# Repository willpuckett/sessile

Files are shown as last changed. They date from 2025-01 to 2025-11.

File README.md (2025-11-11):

# 🧽 Sessile

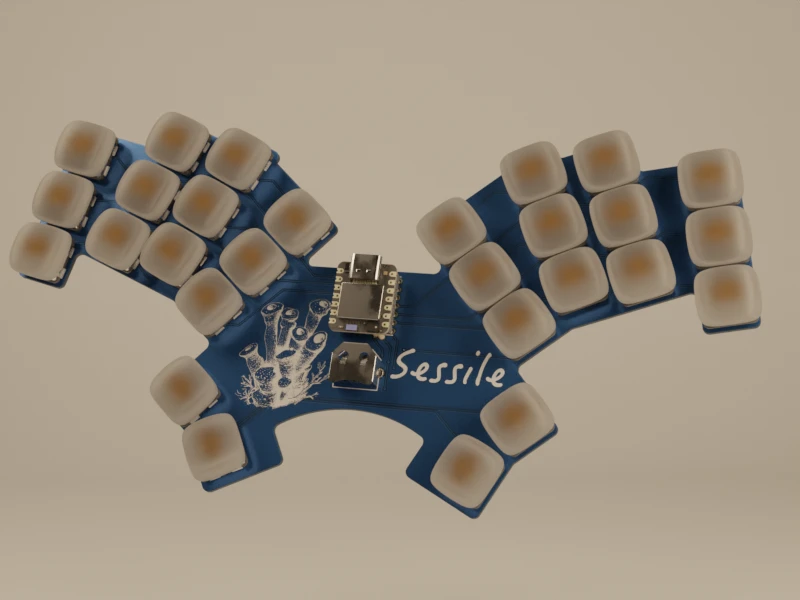
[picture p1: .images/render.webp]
sessile render








_Sessile_ is a further exploration of "minimal" finger travel.

## 🤔 What Even Is 'Minimal Finger Travel' Anyway?

Probably the least amount of finger travel would be not moving them at all. That
would be 10 keys...

```math
combos_{10\,keys} = \sum_{r=1}^{10} C(10, r) = 1023
```

...yielding **1023** possible combinations.

More realistically, we might consider excluding cross hand combinations so that
modifiers might be used. That would give us

```math
combos_{5\,keys} = \sum_{r=1}^{5} C(5, r) = 31
```

So, with only 5 keys on both hands, and no cross hand combos, we would have a
total of **62** possible keys per layer—more than sufficient.

I wasn't quite ready to take on learning to type on that though, so just
avoiding lateral reaches seemed like a start. 🙃

## ✨ Features

- 🧩 Sessile uses
  [KLP-Lame keycaps](https://github.com/braindefender/KLP-Lame-Keycaps). Larger
  caps may be tight, especially on the bottom row. I was lazy and didn't model
  the tilted keycaps in the rendering, but they're much nicer for the vertical
  combos.

- 🔋 Uses battery LIR1254. **DO NOT substitute LR44.**

- 🔌 The high speed pins were left available for encoders and _could_ be wired
  in a subsequent revision.

- ⚙️ Built for RMK. Configure using [Vial](https://get.vial.today).

## 🏠 Case

A 3D printable case is available in the
[latest release](https://github.com/willpuckett/sessile/releases/latest)! The
case is designed to sit as low as possible and can be secured with a stroke of
glue stick underneath. Case is generated via ergogen with jscad v2 api.
[Try it out](https://github.com/ergogen/ergogen/pull/159) it's testing 10-20x
faster than @jscad/cli@1.



## 📦 Production Files

Ready to manufacture your own board? All production files are included in the
repository:



Includes gerbers, BOM, and CPL files for JLC. Finished boards are ~~available~~
[sold out](https://octule.com/listing/1842172090/sessile) till the next batch.

## 🎨 Origin

_Sessile_ was produced using
[studyofhands](https://github.com/willpuckett/studyofhands).

study of hands

## 🚀 Firmware

This board is designed for RMK. 😏

### 🦀 RMK

Current RMK build is available in the
[Releases](https://github.com/willpuckett/sessile/releases/latest).

You can build the firmware yourself by cloning this repository and running

```bash
cd rmk && cargo make uf2 --release
```

> [!TIP]
> If you haven't previously used Rust to build software for nRF52840, you may
> need to follow the
> [Setup RMK Environment](https://rmk.rs/guide/user_guide/2-2_local_compilation#setup-rmk-environment)
> instructions.

## 🗺️ Keymap

<div align="center">

Caster Befuddle Variant

Generated with
[keymap-drawer](https://github.com/caksoylar/keymap-drawer/tree/main).

Physical layout imported from KiCad via
[keymap-layout-tools](https://nickcoutsos.github.io/keymap-layout-tools/).

</div>

## 🔌 Matrix Diagram

Sessile uses the following pinout for its matrix:

sessile_matrix

> [!NOTE]
> Referencing
> [this pinout sheet provided by Seeed](https://files.seeedstudio.com/wiki/XIAO-BLE/XIAO-nRF52840-pinout_sheet.xlsx),
> the only two exposed high speed pins P0_04/SDA/D4 & P0_05/SCL/D5 have been
> left available for possible encoders in a subsequent revision.

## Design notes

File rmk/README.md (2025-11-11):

# 🦀 RMK Firmware






## 🚀 Building

Automated builds of RMK are available in
[releases](https://github.com/willpuckett/sessile/releases/latest).

Once flashed, they can be configured via [Vial](https://get.vial.today).

### 🛠️ Build It Yourself

If you wish to build RMK yourself:

1. 📦 Install Rust: https://rustup.rs
2. 🎯 Add the target: `rustup target add thumbv7em-none-eabihf`
3. 🔧 Install tools: `cargo install flip-link cargo-make`
4. 🏗️ Build: `cd rmk && cargo make uf2 --release`
5. 📤 Flash: Double tap the button on your XIAO to enter the bootloader and drag
   the `.uf2` file to the mounted disk

## 💡 Tips for nRF52840

Most nice!nano compatible boards have a bootloader with SoftDevice pre-flashed.

> [!CAUTION]
> Since v0.7.x, RMK removes the old SoftDevice Bluetooth stack and replaces it
> with its own.
>
> If you want to rollback to v0.6.x, or switch to firmwares that use the
> SoftDevice stack (for example, ZMK), you will need to
> [re-flash the bootloader](https://github.com/willpuckett/sessile?tab=readme-ov-file#zmk).

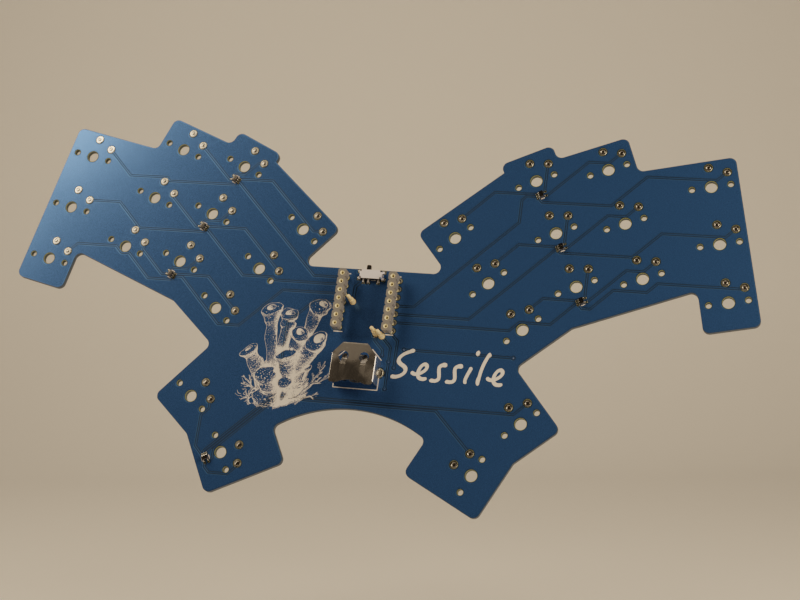
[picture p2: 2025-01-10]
.images/render_board.png

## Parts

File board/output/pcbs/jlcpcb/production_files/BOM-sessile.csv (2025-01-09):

Comment | Designator | Footprint | LCSC | Quantity
mill-max-3305-0-15-01-47-XX-10-0 | J10,J11,J12,J13,J14,J15,J16,J17,J18,J19,J20,J21,J22,J23,J24,J25,J26,J27,J28,J29,J30,J31,J32,J33,J34,J35,J36,J37,J38,J39,J4,J40,J41,J42,J43,J44,J45,J46,J47,J48,J49,J5,J50,J51,J52,J53,J54,J55,J56,J57,J58,J59,J6,J7,J8,J9 | mill-max-3305-0-15-01-47-XX-10-0 | C17370797 | 56
 | SW1 | power_switch | C221841 | 1
HDR-TH_7P-P2.54-V-F_MF254V-11-07-0743 | J60,J61 | HDR-TH_7P-P2.54-V-F_MF254V-11-07-0743 | C2889988 | 2
UMP1NTR | D3,D4,D5,D6,D7,D8,D9 | SOT-353_L2.1-W1.3-P0.65-LS2.3-BL | C510065 | 7
0906-2-15-20-75-14-11-0 | J1,J2,J3 | 0906-2-15-20-75-14-11-0 | C5261048 | 3
CONN-TH_MY-LR44-03-J | BAT1 | CONN-TH_MY-LR44-03-J | C5457116 | 1

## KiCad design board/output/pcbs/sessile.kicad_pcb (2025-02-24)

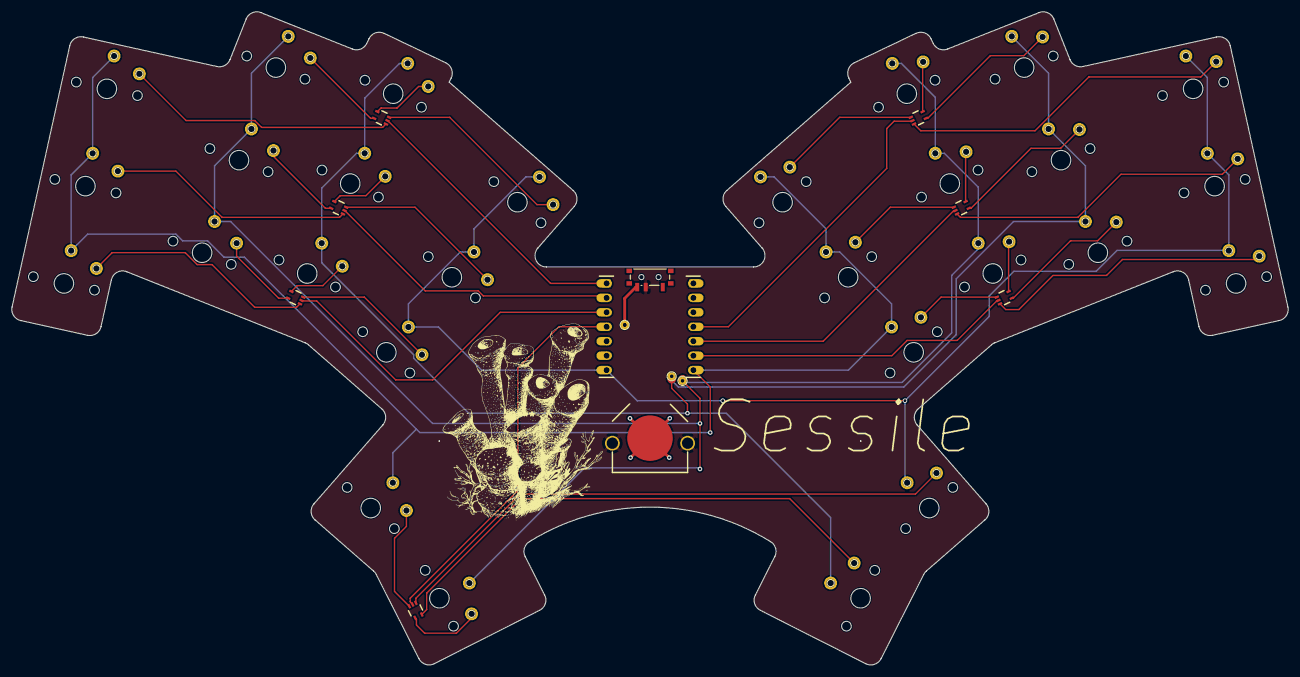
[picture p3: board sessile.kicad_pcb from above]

Board: 2 copper layers, 224.2 x 114.7 mm, 99 parts (0 on the bottom side), 46 nets.

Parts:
BAT1: CONN-TH_MY-LR44-03-J
D3, D4, D5, D6, D7, D8, D9: UMP1NTR; SOT-353_L2.1-W1.3-P0.65-LS2.3-BL
J1, J2, J3: 0906-2-15-20-75-14-11-0
J4, J5, J6, J7, J8, J9, J10, J11, J12, J13, J14, J15, J16, J17, J18, J19, J20, J21, J22, J23, J24, J25, J26, J27, J28, J29, J30, J31, J32, J33, J34, J35, J36, J37, J38, J39, J40, J41, J42, J43, J44, J45, J46, J47, J48, J49, J50, J51, J52, J53, J54, J55, J56, J57, J58, J59: mill-max-3305-0-15-01-47-XX-10-0
J60, J61: HDR-TH_7P-P2.54-V-F_MF254V-11-07-0743
MCU1: xiao-ble
S1, S2, S3, S4, S5, S6, S7, S8, S9, S10, S11, S12, S13, S14, S15, S16, S17, S18, S19, S20, S21, S22, S23, S24, S25, S26, S27, S28: PG1350_KLP_LAME
SW1: power_switch

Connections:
GND: BAT1.2, J61.2, MCU1.2
NFC0: J2.1, J10.1, J11.1, J12.1, J19.1, J20.1, J21.1, J31.1, MCU1.8, S7.2, S8.2, S9.2, S16.2, S17.2, S18.2, S28.2
NFC1: J3.1, J7.1, J8.1, J9.1, J22.1, J23.1, J24.1, J29.1, MCU1.9, S4.2, S5.2, S6.2, S19.2, S20.2, S21.2, S26.2
P0: D5.2, J60.1, MCU1.18
P1: D4.2, J60.2, MCU1.17
P2: D3.2, J60.3, MCU1.16
P3: D9.2, J60.4, MCU1.15
P4: J60.5, MCU1.14
P5: J60.6, MCU1.13
P6: J13.1, J14.1, J15.1, J16.1, J17.1, J18.1, J30.1, J60.7, MCU1.12, S10.2, S11.2, S12.2, S13.2, S14.2, S15.2, S27.2
P7: J4.1, J5.1, J6.1, J25.1, J26.1, J27.1, J28.1, J61.7, MCU1.7, S1.2, S2.2, S3.2, S22.2, S23.2, S24.2, S25.2
P8: D6.2, J61.6, MCU1.6
P9: D7.2, J61.5, MCU1.5
P10: D8.2, J61.4, MCU1.4
RAW: J1.1, MCU1.21, SW1.3
VBAT: BAT1.1, SW1.2
VCC3: J61.3, MCU1.3
VCC5: J61.1, MCU1.1
index_bottom: D3.3, J41.1, S10.1
index_home: D4.3, J42.1, S11.1
index_top: D5.3, J43.1, S12.1
middle_bottom: D3.4, J38.1, S7.1
middle_home: D4.4, J39.1, S8.1
middle_top: D5.4, J40.1, S9.1
mirror_index_bottom: D6.1, J53.1, S22.1
mirror_index_home: D7.1, J54.1, S23.1
mirror_index_top: D8.1, J55.1, S24.1
mirror_middle_bottom: D6.5, J50.1, S19.1
mirror_middle_home: D7.5, J51.1, S20.1
mirror_middle_top: D8.5, J52.1, S21.1
mirror_pinky_bottom: D6.3, J44.1, S13.1
mirror_pinky_home: D7.3, J45.1, S14.1
mirror_pinky_top: D8.3, J46.1, S15.1
mirror_reachy_default: D9.5, J59.1, S28.1
mirror_ring_bottom: D6.4, J47.1, S16.1
mirror_ring_home: D7.4, J48.1, S17.1
mirror_ring_top: D8.4, J49.1, S18.1
mirror_tucky_default: D9.1, J58.1, S27.1
pinky_bottom: D3.1, J32.1, S1.1
pinky_home: D4.1, J33.1, S2.1
pinky_top: D5.1, J34.1, S3.1
reachy_default: D9.4, J57.1, S26.1
ring_bottom: D3.5, J35.1, S4.1
ring_home: D4.5, J36.1, S5.1
ring_top: D5.5, J37.1, S6.1
tucky_default: D9.3, J56.1, S25.1

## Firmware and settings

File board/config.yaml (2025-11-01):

# Very much adapted from Kyle Mitchell's berylline https://github.com/jcmkk3/trochilidae

# 3305's go at 
# x-5 y3.8
# x0 y5.9
# they extend 1.20 below board

# choc footprint holes have been checked for size
# all npth are correct
# pth are too small for 3305s, but placing 3305s over them cuts the
# larger hole, so they don't need to be changed

meta:
  engine: 4.1.0
  name: sessile
  version: 0.1
  author: willpuckett
  url: https://github.com/willpuckett/sessile

presets:
  # These presets provide different layout options
  # Select a preset in the `units` section below
  # Note: The appropriate switch footprint will still need to be set in the `pcb` section
  choc_spaced:
    capx: 17.5        # Key cap size horizontal
    capy: 16.5       # Key cap size vertical
    kx: 18.5        # Key spacing horizontal
    ky: 17.5        # Key spacing vertical
    pinky_splay: 9.26  # Degrees of splay between pinky and ring columns
    ring_splay: 3.84
    middle_splay: 15.58
    thumb_offsetx: 0.25kx

units:
  $extends: presets.choc_spaced
  angle: 12.7755 * 2  # Angle between halves

  # Defaults/Constants
  # ====================
  $default_height: 0  # Points invisible by default unless height/width explicitly set
  $default_width: 0
  xiao_x: 17.8
  xiao_y: 21
  sf: 16
  case_thickness: 1

points:
  zones.matrix:
    anchor.shift: [100, -100]  # Fix placement on KiCAD sheet
    rotate: -angle + pinky_splay + ring_splay 
    mirror:
      ref: matrix_index_top
      shift: [0.5sf, 0.5sf]
      distance: 24
    key:
      width: capx
      height: capy
      spread: kx      
      padding: ky
      autobind: 0
    rows:
      bottom:
        row_net: P2
      home:
        row_net: P1
      top:
        row_net: P0
      bottom.mirror:
        row_net: P8
      home.mirror:
        row_net: P9
      top.mirror:
        row_net: P10

    columns.pinky:
      key:
        column_net: P7
        mirror.column_net: P6
      rows:
        bottom:
          bind: [0.5ky, 0, 0, 0]
        home:
          bind: [0.5ky, 0.5kx, 0, 0]
        top:
          bind: [0, 0.8kx, 0.5ky, 0]

    columns.ring:
      key:
        spread: 22.54
        stagger: 10.5
        splay: -pinky_splay
        # origin: [0, pinky_adj]
        column_net: NFC1
        mirror.column_net: NFC0
      rows:
        bottom:
          bind: [0.5ky, 1.5kx, 0, 0.5kx]
        home:
          bind: [0, 0.5kx, 0, 0]
        top:
          bind: [0, 0.5kx, 0.5ky, 0]
    columns.middle:
      key:
        spread: 18.5
        stagger: 3.44
        splay: -ring_splay
        # origin: [0, ring_adj]
        column_net: NFC0
        mirror.column_net: NFC1
      rows:
        bottom:
          bind: [0.5ky, 0.5kx, 0, 0.5kx]
        home:
          bind: [0, 0.5kx, 0, 0]
        top:
          bind: [0.05ky, 0, 0.5ky, 0]
    columns.index:
      key:
        spread: 18.5
        stagger: -6.5
        splay: -middle_splay
        #origin: [0, index_adj]
        column_net: P6
        mirror.column_net: P7
      rows:
        bottom:
          bind: [0.5ky, 0.5kx, 0, 0.5kx]
        home:
          bind: [0.5ky, 0, 0, 0]
        top:
          bind: [0, 0, 0.5ky, 0.85kx]
  zones.thumb:
    anchor:
      ref: matrix_index_bottom
      shift: [15.93, -22.4]
    mirror.$extends: points.zones.matrix.mirror
    key.$extends: points.zones.matrix.key
    columns:
      tucky:
        key:
          bind: [0.5ky, 0.5kx, 0, 0]
          row_net: P3
          column_net: P7
        key.mirror:
          row_net: P3
          column_net: P6
      reachy:
        key:
          stagger: -4
          splay: -22
          spread: kx + 1
          bind: [0.5ky, 0.1kx, 0, 0.5kx]
          row_net: P3
          column_net: NFC1
        key.mirror:
          row_net: P3
          column_net: NFC0
  zones.reference_top_center:
    anchor:
      aggregate.parts: [matrix_index_top, mirror_matrix_index_top]
      shift: [0, -0.65ky]
  zones.mcu:
    anchor:
      ref: reference_top_center
      shift: [0, -0.5xiao_y]
    key:
      width: xiao_x
      height: xiao_y
  zones.mounting_hole:
    anchor:
      ref: matrix_index_home
      shift: [-0.5kx + 4, -ky + 4]
    mirror.$extends: points.zones.matrix.mirror
    key:
      width: 1
      height: 1
outlines:
    _key_outline:
      - what: rectangle
        bound: true
        size: sf
        where:
          - /matrix_.*/
          - /thumb_.*/
    _switch_holes:
      - what: circle
        radius: 2.15
        where:
          - /matrix_.*/
          - /thumb_.*/
      - what: circle
        radius: 1.5
        adjust:
          shift: [-5.5, 0]
        where:
          - /matrix_.*/
          - /thumb_.*/
      - what: circle
        radius: 1.5
        adjust:
          shift: [5.5, 0]
        where:
          - /matrix_.*/
          - /thumb_.*/
      - what: circle
        radius: 1.5
        adjust:
          shift: [0, 5.9]
          resist: true
        where:
          - /matrix_.*/
          - /thumb_.*/
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

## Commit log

2025-01-09 add outputs for actual board
    [BOM-sessile.csv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]
2025-01-10 re-render production files
    [CPL-sessile.csv, sessile-CuBottom.gbr, sessile-CuTop.gbr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]
2025-05-15 add stl model
2025-07-05 RMK becomes daily driver
2025-07-11 build without battery_adc_pin
2025-09-15 change brackets
2025-09-26 add brackets set
2025-10-11 add battery reporting
2025-10-29 add scrolllock configuration to keyboard settings for battery reading
2025-10-29 Bump version to 0.3.0 and update dependencies
    - Updated the version in Cargo.toml from 0.2.0 to 0.3.0.
    - Updated nrf-sdc and nrf-mpsl dependencies to the latest commit (11d5c3c).
    - Upgraded bt-hci dependency version from 0.5 to 0.6.
    - Updated embassy-nrf dependency version from 0.7 to 0.8.
    Refactor keyboard.toml configuration for compatability with PR593
    - Changed input/output pins to row/column pins in the matrix configuration.
    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
2025-10-30 switch RCtrl to LCtrl for better terminal compatability
2025-10-31 Update sessile_study.svg dimensions and metadata
    - Changed SVG dimensions from 334mm x 200mm to 236.65063mm x 128.68333mm.
    - Updated document name to "sessile_study.svg".
    - Updated Inkscape version to 1.4.2 (ebf0e940, 2025-05-08).
    - Adjusted Inkscape window properties for better usability.
    - Modified image transformation parameters for improved layout.
2025-11-01 fix: use ergogen for case creation
    [case.step, sessile_case.3mf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]
2025-11-01 Add GitHub Actions workflow for building and releasing board case
2025-11-01 refactor: update build process and scripts for case generation
2025-11-02 fix: update GitHub Actions workflow for case build and release paths
2025-11-02 fix: update dev script to use pcbnew directly instead of full path
2025-11-06 fix: update KiBot action version and adjust configuration for board variant
2025-11-06 feat: add dummy schematic creation to KiBot workflow and update configuration in sessile.kibot.yaml
2025-11-06 fix: uncomment board and schema parameters in KiBot workflow configuration
2025-11-06 fix: reorder steps in KIBOT job for proper execution flow
2025-11-06 fix: update KiBot workflow to streamline job steps and improve execution flow
2025-11-06 fix: add dummy schematic creation step in KiBot workflow
2025-11-11 fix: update README and add LICENSE file with Solderpad Hardware License v2.1
2025-11-11 fix: improve formatting and readability in README for case and production files sections

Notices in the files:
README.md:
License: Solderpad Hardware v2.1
